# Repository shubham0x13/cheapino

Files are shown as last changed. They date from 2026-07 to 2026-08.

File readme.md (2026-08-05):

Cheapino
========

> [!NOTE]
> This is the `personal-build` branch — documenting the case mods I made and the parts/sources I used for my own **v2** build (India-based sourcing). See the [build notes](doc/personal_build.md) for details. For the original project, switch to the [`master` branch](../../tree/master) or visit the [upstream repository](https://github.com/tompi/cheapino).

Probably one of the cheapest split keyboards you can build.

V2 in case
V2 in case

This is the result of really enjoying building keyboards,
but not wanting to spend that much money on it.
The pcb is reversible, connected using rj45,
and utilizes a japanese duplex matrix, so only one
mcu is needed. For hotswap I recommend a case(pictured above),
but soldering the switches is of course the cheapest option :)

You want one?
See the [ordering guide](doc/orderingguide.md) for what you need and how to buy it.

See the [build guide v2](doc/buildguide_v2.md) for more details and pictures of how to actually build it.

Some info on the [plate/case solutions](doc/plates_and_cases.md) I know about.

Checkout the [troubleshooting guide](doc/troubleshooting.md) if your Cheapino does not work.

See the [firmware guide](doc/firmware.md) for how to build and customize keyboard firmware.
The cheapino has vial support, or you can build your own QMK to customize EVERYTHING.
Even the onboard RP2040-Zero LED is controllable by QMK...

I added [a few tips and tricks here](doc/tips.md).

[Loads of beautiful build pictures here.](doc/gallery.md)

# License

This work is licensed under a [Creative Commons Attribution license.](LICENSE.txt)

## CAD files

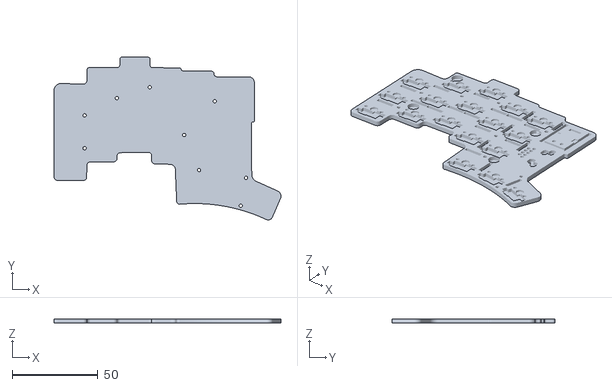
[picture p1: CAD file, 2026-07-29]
case/stls/cheapino-bottom-left.stl
132.5 x 95.1 x 2.50

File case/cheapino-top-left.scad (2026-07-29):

height = 95.1738;
width = 132.6134;
step = 0.04;
$fn = $preview ? 10 : 50;

height_translation = 0;
include <modules.scad>

// Rotate so you dont need to do that in extruder
translate([0,0,9.1])
rotate([0,180,0])
difference() {
  case();
  linear_extrude(4.1) offset(delta=0.45) base();

  // For debug: comment out above 3 lines and comment in this
  //translate([0,0,4.1])
  //      board();

translate([0,0,top_of_pcb]) switch_holes();

// Diodes
translate([0, 0, top_of_pcb]) diodes();

// RJ45 socket
color("cyan") {
    translate([29.2, -10.6, 2.5])
    linear_extrude(10)
    square([30, 16.6]);
}

mcu_cutout();
// mounting holes
mounting_hole_inserts();

}

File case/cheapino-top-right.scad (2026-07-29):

height = 95.1738;
width = 132.6134;
step = 0.04;
$fn = $preview ? 10 : 50;

height_translation = 0;
include <modules.scad>


// Rotate so you dont need to do that in extruder
translate([0,0,9.1])
rotate([0,180,0])
mirror() {
  difference() {
    case();
    linear_extrude(4.1) offset(delta=0.45) base();

    // holes and shape for debug
    //translate([0,0,4.1])
    //    board();

    translate([0,0,top_of_pcb]) switch_holes();

    // Diodes
    translate([0, 0, top_of_pcb]) diodes();

    // RJ45 socket
    color("cyan") {
        translate([29.2, -9.33, 2.5])
        linear_extrude(10)
        square([30, 16.6]);
    }


    // EC11 encoder
    color("pink") {
        translate([32.75, 15.5, 4.1])
        linear_extrude(10)
        square([13, 14.6]);

        translate([32.2, 14, 4.1])
        linear_extrude(3)
        square([14.2, 17.5]);
    }

    // solder bridge pads needs some space
    color("red")
    translate([29, -15.53, 4.1])
    linear_extrude(2)
    square([19.5, 3.5]);


    mounting_hole_inserts();
  }
}

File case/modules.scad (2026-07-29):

pcb_thickness = 1.6;
bottom_plate_thickness = 2.5;
top_of_pcb = bottom_plate_thickness + pcb_thickness;

cover_radius = 2;
rj45_height = 13;
mcu_height = 9; // mcu + hotswap

// bottom plate
module bottom()
{
color("pink")
translate([0,0,0])
  linear_extrude(bottom_plate_thickness)
    offset( delta=0)
       base();
}

module base()
{
	import ("plate.svg", center=true);
}

module board()
{
    color("#1f77b4")
    translate([0,0,-1.6])
    linear_extrude(1.6)
    rotate([0,180,0])
    import("cheapino-brd.svg", center=true);
}

module hotswap_mx() {
    thickness=1.85;

    // Holes
    translate([3.175,2.2,0])
    linear_extrude(height=3.05)
        circle(d=3);

    translate([-3.175,-0.36,0])
    linear_extrude(height=3.05)
        circle(d=3);

    // Body
    linear_extrude(height=thickness)
    square([11.8,5.2], center=true);

    translate([0,2,0])
    linear_extrude(height=thickness)
    square([5.65, 2.39]);

    translate([-5.9,-3,0])
    linear_extrude(height=thickness)
    square([5.65, 2.39]);

    
    // Metal soldering parts
    translate([5.45,1.04,0])
    linear_extrude(height=thickness)
    square([2.5, 2.55]);

    translate([-7.95,-1.7,0])
    linear_extrude(height=thickness)
    square([2.5, 2.55]);
}


module column(bottom) {
switch(bottom);

translate([0, 19, 0]) switch(bottom);

translate([0, 38, 0]) switch(bottom);
}

module switch(bottom) {
  // hotswap socket
  color("#ff7f0e")
  translate([0,bottom ? -9.42 : 0,1.85])
  rotate([180,0,0])
  mirror([0,bottom ? 1 : 0,0])
    hotswap_mx();

  // main pin of switch
  // 4mm d, 2.8mm high, 1.6mm pcb
  // means 1.2 of it sticks below, 1.3 for margin
  color("#2ca02c")
  translate([-0.57, -4.7, 0])
  linear_extrude(height=1)
  circle(d=4.2);



  // The two switch alignment pins
  // They will need to be snipped if too long
  color("#d62728")
  translate([-5.74, -4.7, 0])
  linear_extrude(height=1)
  circle(d=1.8);

  color("#d62728")
  translate([4.45, -4.7, 0])
  linear_extrude(height=1)
  circle(d=1.8);

}

module diode() {
color("#8c564b")
linear_extrude(height=1.85)
square([9.9, 2]);
}

module rdiode() {
  rotate(90)
  diode();
}



module magsafe_ring()
{
translate([0,0,0])
linear_extrude(height=1.4)
difference() {
    circle(d=55.1);
    circle(d=44.9);
  }
}


module rj_hole() {
color("#e377c2")
  linear_extrude(1.7) {
  translate([40.1,3.5,0])
  circle(d=3.5);
  translate([40.1,4.8,0])
  circle(d=3.5);
  }
}

module rj_pin_hole() {
  color("#e377c2")
  linear_extrude(1.3)
  translate([33.7,3.5,0])
  circle(d=2);
}

module encoder() {
    color("#7f7f00")
    linear_extrude(0.6) {
        translate([35.7, 29.8])
        square([7,2]);
        translate([32.65, 21.6])
        square([2, 3.3]);
        translate([43.85, 21.6])
        square([2, 3.3]);
    }
    color("#7f0000")
    linear_extrude(1) {
        translate([35.7, 29.8])
        square([7,2]);
        translate([36.8, 16.3])
        circle(d=2);
        translate([41.77, 16.3])
        circle(d=2);
    }
}

module mcu() {
    color("#7f7f7f")
    linear_extrude(1.5) {
    translate([30.65, 11.5])
    square([2,22.5]);
    translate([45.83, 11.5])
    square([2,22.5]);
    }

    color("#7f7f7f")
    linear_extrude(1)
    translate([31.65, 11.5])
    square([15,2]);
}

module mounting_hole() {
    color("#bcbd22")
    translate([45.85, -23, 0]) {
      cylinder(h=0.7, d=2);
      
      translate([0,0,0.7])
      cylinder(h=1.5, d1=2, d2=4);
      
      translate([0,0,2.2])
      cylinder(h=0.3, d=4);
    }
}

module bumper() {
    color("#17becf")
    translate([41, 29, 1.25])
    cylinder(h=1.25, d=8.15);
}

module magnet() {
    color("#9467bd")
    cylinder(h=2.1, d=6.1);
}

module switches(bottom) {
    // Columns starting from MCU
    translate([19.3,-2.84,0])
    column(bottom);

    //rotate([0,0,180])
    translate([0.3,-0.3,0])
    column(bottom);

    translate([-18.7,6.05,0])
    column(bottom);

    translate([-37.7,-0.3,0])
    column(bottom);

    translate([-56.7,-10.308,0])
    column(bottom);

    // Thumb cluster
    translate([14.6264,-24.52])
    switch(bottom);

    rotate([0,0,-10])
    translate([40.3,-19.3])
    switch(bottom);

    rotate([0,0,-23])
    translate([65.65,-7.09])
    switch(bottom);
}

module diodes() {
    // The horizontal diodes
    translate([-18.2, 10.01, 0]) diode();
    translate([-28.79, 10.01, 0]) diode();
    translate([-26.43, 28.98, 0]) diode();
    translate([-9.663,21.77,0]) diode();
    translate([0.8, 21.77, 0]) diode();
    translate([13.906, 19.672, 0]) diode();
    translate([15.938,0.866,0]) diode();
    translate([5.688,-19.328,0]) diode();
    translate([-5.218, 2.771, 0]) diode();
    translate([-37.467,3.355,0]) diode();
    translate([-47.827,3.355,0]) diode();
    translate([-61.434,11.813,0]) diode();
    translate([-61.8,-7.211,0]) diode();
    translate([-47.816,22.304,0]) diode();

    // The vertical(ish) diodes
    translate([10.81, 24.5, 0]) rdiode();
    translate([10.785, 6.861, 0]) rdiode();
    translate([29.86, 24.906, 0]) rdiode();
    translate([28.565, -2.935, 0]) rdiode();
    translate([10.785, -13.346, 0]) rdiode();
    translate([26.177, -31.38, 0]) rdiode();

    translate([46.58, -35.6, 0])
    rotate(76)
    diode();
}

module rj45() {
    // rj 45 stabilizers
    rj_hole();
    translate([0,-11.43,0]) rj_hole();

    // rj 45 housing through holes
    translate([3.1,2,0]) rj_hole();
    translate([3.1,-13.49,0]) rj_hole();

    // rj 45 pins
    rj_pin_hole();
    translate([0,-2.54,0]) rj_pin_hole();
    translate([0, -5.08,0]) rj_pin_hole();
    translate([0,-7.62,0]) rj_pin_hole();
    translate([0,-10.16,0]) rj_pin_hole();
    translate([-2.54,-1.27,0]) rj_pin_hole();
    translate([-2.54,-3.81,0]) rj_pin_hole();
    translate([-2.54,-6.35,0]) rj_pin_hole();
    translate([-2.54,-8.89,0]) rj_pin_hole();
}

module mounting_holes() {
    // Mounting holes
    mounting_hole();
    translate([-27.432,4.572,0]) mounting_hole();
    translate([-18.288,44.704,0]) mounting_hole();
    translate([-36.132,25.02,0]) mounting_hole();
    translate([-56.183,52.928,0]) mounting_hole();
    translate([-75.399,46.599,0]) mounting_hole();
    translate([-94.267,36.473,0]) mounting_hole();
    translate([-94.241,17.313,0]) mounting_hole();
    translate([-3.048,-16.256,0]) mounting_hole();
}

//color("green")
//translate([0,0,0])
// import("hotswap.stl");

// Height of case is:
//  5.0mm from pcb to switch inset
//  1.6mm pcb height
//  2.5mm bottom plate
//
//  for a total of 9.1mm.
//
// The case only adds 0.7mm extra height
// to the keyboard.
module case() {
    color("red")
    for (i = [0:step:8.1])
    {
        factor = min(3 - abs(i*0.7-3), 1.5);
        //echo(pow(i, 2));
        //echo(factor);
        translate([0,0,i]) //height_translation])
            linear_extrude(height=1)
                offset( delta=factor + 1 )
                    base();
            //base_extended(factor, 1);
    }
}

module switch_holes() {
    // Columns starting from mcu
    hole_column();
    translate([-19, 2.54, 0]) hole_column();
    translate([-38, 8.89, 0]) hole_column();
    translate([-57, 2.54, 0]) hole_column();
    translate([-76, -7.468, 0]) hole_column();

    // Thumb cluster
    translate([-4.674, -59.69, 0]) switch_hole();
    rotate(-10) translate([21, -54.45, 0]) switch_hole();
    rotate(-23) translate([46.25, -42.25, 0]) switch_hole();
}

module hole_column() {
switch_hole();
translate([0, -19, 0]) switch_hole();
translate([0, -38, 0]) switch_hole();
}

module switch_hole() {
  translate([11.64, 23.45, 0]){
    color("green") {
        linear_extrude(10) {
          square(14);
          translate([0.2,0.2,0]) circle(d=1);
          translate([13.8,0.2,0]) circle(d=1);
          translate([13.8,13.8,0]) circle(d=1);
          translate([0.2,13.8,0]) circle(d=1);
        }
      }
      linear_extrude(3.53) {
          translate([4.5, -1, 0])
          color("yellow") square([5, 1]);
          translate([4.5, 14, 0])
          color("yellow") square([5, 1]);
      }
    }
  }

module base()
{
	import ("plate.svg", center=true);
}


module base_line(expanded)
{
  difference()
  {
    offset( delta=expanded+1)
            base();
    offset( delta=expanded)
            base();
  }
}

module mounting_hole_insert() {
    color("#bcbd22")
    translate([45.85, -23, 0]) {
      translate([0,0,4.1])
      
      cylinder(h=4, d=3.65);
    }
}

module mounting_hole_inserts() {
    // Mounting holes
    mounting_hole_insert();
    translate([-27.432,4.572,0]) mounting_hole_insert();
    translate([-18.288,44.704,0]) mounting_hole_insert();
    translate([-36.132,25.02,0]) mounting_hole_insert();
    translate([-56.183,52.928,0]) mounting_hole_insert();
    translate([-75.399,46.599,0]) mounting_hole_insert();
    translate([-94.267,36.473,0]) mounting_hole_insert();
    translate([-94.241,17.313,0]) mounting_hole_insert();
    translate([-3.048,-16.256,0]) mounting_hole_insert();
}
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

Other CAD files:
case/stls/cheapino-bottom-right.stl

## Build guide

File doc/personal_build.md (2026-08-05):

# Cheapino v2: Personal Build Notes

## Case Modifications

This is a **v2 build**. I slightly modified the original case to better suit my preferences — adjusted some tolerances to fit hardware I sourced locally (India) and simplified the geometry for support-free printing.

| Feature | Modification Details |
| :--- | :--- |
| M2 Insert Holes | Diameter changed to `3.65 mm` to perfectly fit standard M2 brass inserts. |
| Rubber-Foot Pockets | Resized for 8×2 mm (or 8×3 mm) silicone bumpers. |
| Countersinks | Added a 3-tier countersink to ensure M2 CSK screws seat perfectly flush. |
| Switch Clips | Reduced cutout thickness to `1.45 mm` for a tighter, more secure grip on the switches. |
| Case Chamfer | Reduced the outer edge chamfer (personal preference). |
| RJ45 Cutout | Simplified the overhang geometry to allow completely support-free printing. |

## 3D Printing

**Bambu Studio project:** [`case/print-profiles/cheapino-case-bambu.3mf`](../case/print-profiles/cheapino-case-bambu.3mf)

I have included a pre-configured print profile for Bambu Lab printers. The `.3mf` file contains the full 4-part plate arranged so **no supports are needed**.

It also includes two variants of a custom flush-fit encoder knob (D-shaft and round/knurled for a 15 mm shaft) designed to sit close to the top of the case. Print the knob that matches your specific EC11 encoder.

If the fit needs adjusting, you can grab the source `.step` or `.f3d` files for the knob from [Printables](https://www.printables.com/model/1794223).

## PCB Fabrication

For how to order (uploading gerbers, settings, etc.), see the [ordering guide](orderingguide.md#the-pcb).

For India, use [Robu.in](https://robu.in/pcb-manufacturing/) or [Zbotic.in](https://zbotic.in/pcb-manufacturing/), which proxy your order to JLCPCB while handling shipping and customs. Ordering from JLCPCB directly might be cheaper but customs clearance in India is unpredictable, so probably not worth the risk.

## Bill of Materials

### Electronics

| Part | Qty | Description/Notes | Sourcing Links |
| :--- | ---: | :--- | :--- |
| Waveshare RP2040-Zero | 1 | **Must NOT** have pre-soldered headers. | [Robu (Original)](https://robu.in/product/waveshare-rp2040-zero-without-header/), [Robu (Clone)](https://robu.in/product/rp2040-zero-for-raspberry-pi-microcontroller-with-soldering/) |
| Male Pin Headers | 1 | 2.54 mm 1×40 straight strip. | [Robu](https://robu.in/product/2-54mm-1x40-pin-male-single-row-straight-short-header-strip-pack-of-3/) |
| 1N4148 Diodes | 42 | Through-hole. One per key + a few spares. | [Vishaworld](https://vishaworld.com/products/1n4148-diode), [Robu](https://robu.in/product/1n4148-1w-zener-diode-pack-of-50) |
| EC11 Rotary Encoder | 1 | 15 mm shaft. Match your 3D printed knob to the shaft type. | [Robu (D-shaft)](https://robu.in/product/hongyan-ec11h-7ce15p1zd15f7-rotary-encoder-with-push-button-switch-vertical-plug-in-5-pin-360-degree/), [Robu (Round)](https://robu.in/product/hongyan-ec11h-7ce15p1zy15f7-rotary-encoder-with-push-button-switch-vertical-plug-in/) |

### Hardware (Case Assembly)

| Part | Qty | Description/Notes | Sourcing Links |
| :--- | ---: | :--- | :--- |
| M2 Brass Heatset Inserts | 18 | M2 × 4 mm, OD 3.8 mm (Tested in this build). | [OnlyScrews](https://onlyscrews.in/products/m2-x-4mm-brass-threaded-inserts) |
| M2 Brass Heatset Inserts | 18 | M2 × 3 mm, OD 3.8 mm (Alternative, untested). | [OnlyScrews](https://onlyscrews.in/products/m2-x-3mm-brass-threaded-inserts) |
| M2 Countersunk Screws | 18 | M2 × 6 mm, Phillips flat head (Sits flush with case). | [OnlyScrews](https://onlyscrews.in/products/m2-x-6mm-phillips-csk-ss-304-screw-dia-2mm-length-6mm) |
| Silicone Rubber Feet | 8 | 8×2 mm (or 8×3 mm) tall. | [Amazon](https://www.amazon.in/gp/product/B083DTH5HL) |
| Flush-fit Knob | 1 | 3D printed part. | [Printables](https://www.printables.com/model/1794223) |

## Related Docs

* [Ordering guide](orderingguide.md) — Full electronics BOM with AliExpress links.
* [Case build guide](case_buildguide.md) — Assembly instructions, heat-set install, and screw torque.
* [Build guide v2](buildguide_v2.md) — Soldering and PCB assembly.

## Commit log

2026-07-29 feat(case): customize case geometry and tolerances for personal build
    - Simplify RJ45 socket cutout
    - Adjust M2 insert hole diameter to 3.65mm for standard brass inserts (mounting_hole)
    - Resize bottom plate rubber feet bumper cavity (bumper)
    - Redefine 3-tier countersink profile for flush mounting screws (mounting_hole)
    - Adjust case outer side profile curve overhang (case)
    - Reduce switch clip cutout thickness to 1.45mm (switch_hole)
    - Add 3D print profile tuned for Bambu Lab P2S
    [cheapino-bottom-left.stl, cheapino-bottom-right.stl, cheapino-top-left.scad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]
2026-08-05 docs: add personal build notes and organize case assets
    [cheapino-bottom-left.stl, cheapino-bottom-right.stl]

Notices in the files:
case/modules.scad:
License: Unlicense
